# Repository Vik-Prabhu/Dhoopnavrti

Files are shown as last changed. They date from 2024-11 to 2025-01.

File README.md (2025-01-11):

# Dhoopnavarti
Project for a Ayurvedic Medical Ear cleaning device. This device needed temperature and pressure to be monitored and displayed on an oled display. We used STM32L432 MCU for this purpose. Along with these sensores we made a battery monitoring system with the MCU by reading analog values from the battery and displaying it on the oled. The device also readed a charging port of a lighter and the battery for which we used a battery charger with USB. This Repo Includes the PCB designs of the project.

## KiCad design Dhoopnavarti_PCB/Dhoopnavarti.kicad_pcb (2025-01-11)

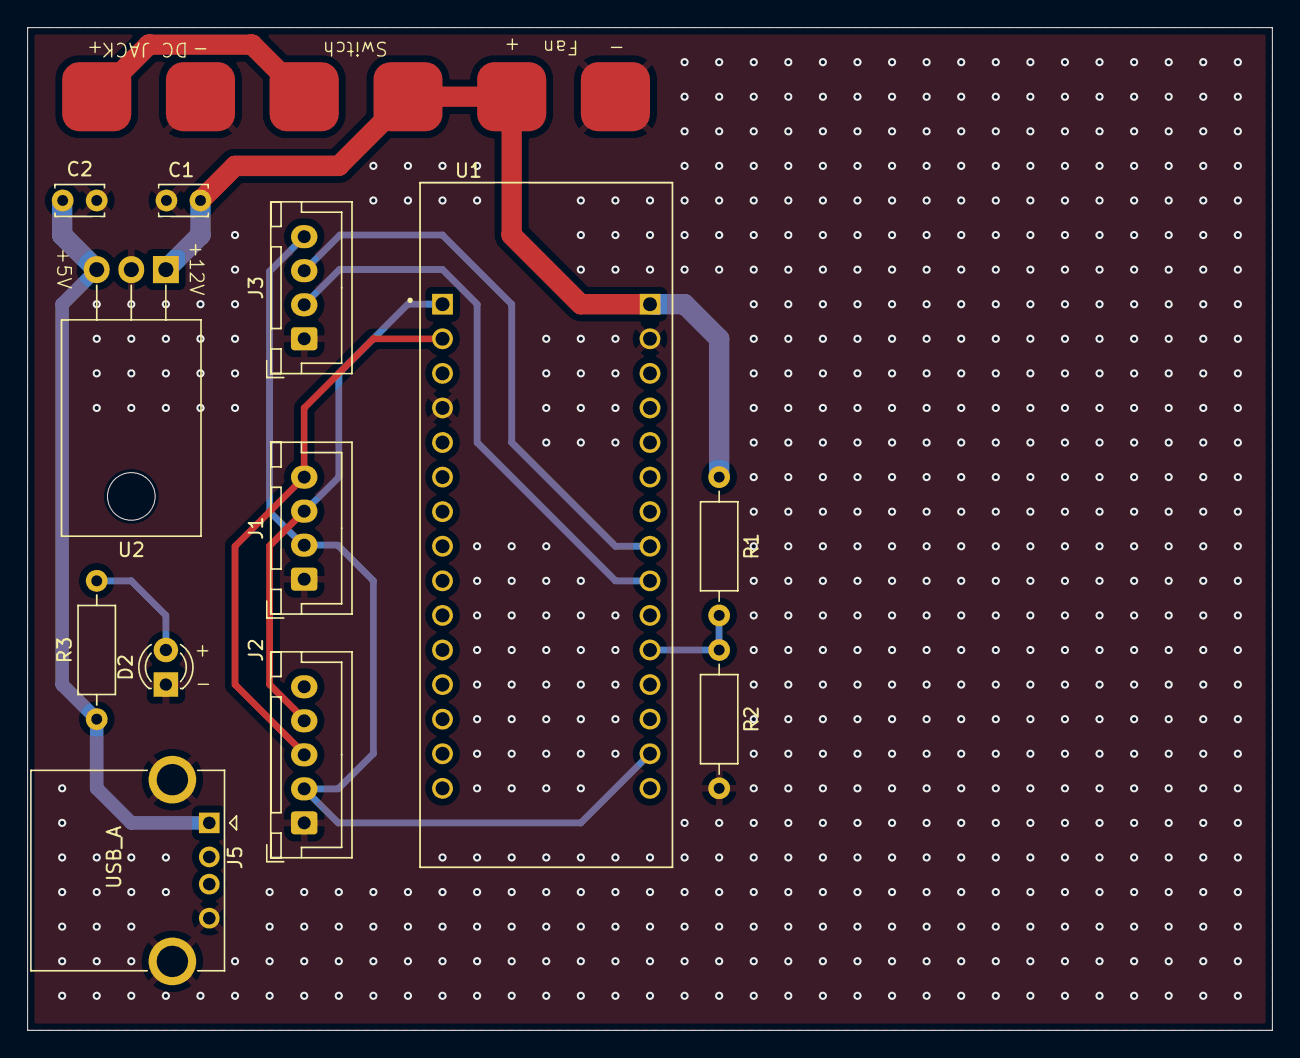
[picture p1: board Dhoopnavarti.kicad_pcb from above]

Board: 2 copper layers, 91.4 x 73.7 mm, 15 parts (0 on the bottom side), 11 nets.

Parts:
C1: 330nF; C_Disc_D3.4mm_W2.1mm_P2.50mm
C2: 100nF; C_Disc_D3.4mm_W2.1mm_P2.50mm
D2: LED; LED_D3.0mm
DC JACK: Screw_Terminal_01x02; Wire_Pad
Fan: Screw_Terminal_01x02; Wire_Pad
J1, J3: Conn_01x04_Pin; JST_XH_B4B-XH-A_1x04_P2.50mm_Vertical
J2: Conn_01x05_Pin; JST_XH_B5B-XH-A_1x05_P2.50mm_Vertical
J5: USB_A; USB_A_Kycon_KUSBX-AS1N-B_Horizontal
R1, R2: R_US; R_Axial_DIN0207_L6.3mm_D2.5mm_P10.16mm_Horizontal
R3: 220; R_Axial_DIN0207_L6.3mm_D2.5mm_P10.16mm_Horizontal
Switch: Screw_Terminal_01x02; Wire_Pad
U1: NUCLEO-L432KC; MODULE_NUCLEO-L432KC
U2: LM7805_TO220; TO-220-3_Horizontal_TabDown

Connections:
+3.3V: J1.2, J2.2, J3.4, U1.CN4_14 (+3V3)
+5V: C2.1, J5.1 (VBUS), R3.1, U2.3 (VO)
+12V: C1.1, Fan.1, R1.1, Switch.2, U1.CN4_1 (VIN), U2.1 (VI)
Battery_+12V: DC JACK.1, Switch.1
GND: C1.2, C2.2, D2.1 (K), DC JACK.2, Fan.2, J1.1, J2.1, J3.1, J5.4 (GND), J5.5 (Shield), R2.2, U1.CN3_4 (GND_CN3), U1.CN4_2 (GND_CN4), U2.2 (GND)
unnamed: D2.2 (A), R3.2
unnamed: R1.2, R2.1, U1.CN4_11 (PA1)
OUT: J3.3, U1.CN4_8 (PA5)
SCK: J3.2, U1.CN4_9 (PA4)
SCL: J1.3, J2.4, U1.CN3_1 (PA9)
SDA: J1.4, J2.3, U1.CN3_2 (PA10)

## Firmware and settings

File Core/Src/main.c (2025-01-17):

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
/* Includes ------------------------------------------------------------------*/
#include "main.h"

/* USER CODE BEGIN Includes */
#include "tmp117.h"
#include "ssd1306.h"
#include "ssd1306_conf.h"
#include "ssd1306_tests.h"
#include "ssd1306_fonts.h"
#include <stdio.h>
#include <string.h>
/* USER CODE END Includes */

/* USER CODE BEGIN PD */
#define HX710B_DATA_GPIO_Port OUT_GPIO_Port
#define HX710B_DATA_Pin OUT_Pin
#define HX710B_CLK_GPIO_Port SCK_GPIO_Port
#define HX710B_CLK_Pin SCK_Pin
/* USER CODE END PD */

ADC_HandleTypeDef hadc1;

I2C_HandleTypeDef hi2c1;
I2C_HandleTypeDef hi2c3;

UART_HandleTypeDef huart2;

/* USER CODE BEGIN PV */
#define TMP117_ADDR          0x48 << 1     // TMP117 address with R/W bit
#define TMP117_TEMP_REG      0x00          // Temperature register
#define TMP117_CONFIG_REG    0x01          // Configuration register

// TMP117 configuration values
#define TMP117_CONFIG_VALUE  0x0220
/* USER CODE END PV */

void SystemClock_Config(void);
static void MX_GPIO_Init(void);
static void MX_I2C1_Init(void);
static void MX_USART2_UART_Init(void);
static void MX_ADC1_Init(void);
static void MX_I2C3_Init(void);
/* USER CODE BEGIN 0 */
// TMP117 Initialization
HAL_StatusTypeDef TMP117_Init(void) {
	uint8_t config_data[3];
	config_data[0] = TMP117_CONFIG_REG;               // Register pointer
	config_data[1] = (TMP117_CONFIG_VALUE >> 8) & 0xFF; // MSB of config
	config_data[2] = TMP117_CONFIG_VALUE & 0xFF;       // LSB of config

	// Write to the configuration register
	return HAL_I2C_Master_Transmit(&hi2c1, TMP117_ADDR, config_data, 3,
			HAL_MAX_DELAY);
}

// Read temperature from TMP117
HAL_StatusTypeDef TMP117_ReadTemperature(float *temperature) {
	uint8_t temp_data[2];
	int16_t raw_temp;

	// Request 2 bytes from temperature register
	temp_data[0] = TMP117_TEMP_REG;
	if (HAL_I2C_Master_Transmit(&hi2c1, TMP117_ADDR, temp_data, 1,
			HAL_MAX_DELAY) != HAL_OK) {
		return HAL_ERROR;  // Error in sending data
	}

	// Receive 2 bytes of temperature data
	if (HAL_I2C_Master_Receive(&hi2c1, TMP117_ADDR, temp_data, 2, HAL_MAX_DELAY)
			!= HAL_OK) {
		return HAL_ERROR;  // Error in receiving data
	}

	// Combine the two bytes to form a 16-bit signed integer
	raw_temp = (int16_t) ((temp_data[0] << 8) | temp_data[1]);

	// Convert to Celsius based on TMP117 resolution (0.0078125 °C per LSB)
	*temperature = raw_temp * 0.0078125;

	return HAL_OK;
}
int _write(int file, char *ptr, int len) {
	int DataIdx;
	for (DataIdx = 0; DataIdx < len; DataIdx++) {
		ITM_SendChar(*ptr++);
	}
	return len;
}

long readHX710B() {
	// Wait until data line is low (indicating data is ready)
	while (HAL_GPIO_ReadPin(HX710B_DATA_GPIO_Port, HX710B_DATA_Pin))
		;

	long result = 0;

	// Read 24 bits from the sensor
	for (int i = 0; i < 24; i++) {
		// Set clock high and then low with small delay for timing
		HAL_GPIO_WritePin(HX710B_CLK_GPIO_Port, HX710B_CLK_Pin, GPIO_PIN_SET);
//        delay_us(1);  // 1 microsecond delay;
//        HAL_Delay(1);
		HAL_GPIO_WritePin(HX710B_CLK_GPIO_Port, HX710B_CLK_Pin, GPIO_PIN_RESET);
//        delay_us(1);  // 1 microsecond delay

		// Shift result left and read data bit
		result = result << 1;
		if (HAL_GPIO_ReadPin(HX710B_DATA_GPIO_Port, HX710B_DATA_Pin)) {
			result++;
		}
	}

	// Convert to two's complement if needed
	result = result ^ 0x800000;

	// Pulse the clock line 3 times to initiate the next reading
	for (char i = 0; i < 3; i++) {
		HAL_GPIO_WritePin(HX710B_CLK_GPIO_Port, HX710B_CLK_Pin, GPIO_PIN_SET);
//        delay_us(1);  // Small delay
//        HAL_Delay(1);
		HAL_GPIO_WritePin(HX710B_CLK_GPIO_Port, HX710B_CLK_Pin, GPIO_PIN_RESET);
//        delay_us(1);  // Small delay
	}

	return result;
}
float mapVoltageToPercentage(float voltage, float minVoltage, float maxVoltage) {
    // Ensure voltage stays within the specified range
    if (voltage < minVoltage) voltage = minVoltage;
    if (voltage > maxVoltage) voltage = maxVoltage;

    // Map the voltage to a percentage
    return ((voltage - minVoltage) / (maxVoltage - minVoltage)) * 100.0;
}
float batterymonitor() {
// Poll for conversion completion and check if the ADC data is ready
	HAL_ADC_Start(&hadc1);
	if (HAL_ADC_PollForConversion(&hadc1, HAL_MAX_DELAY) == HAL_OK) {
		// Get the analog value
		uint32_t adcValue = HAL_ADC_GetValue(&hadc1);

		// Convert ADC value to voltage (assuming 12-bit resolution and 3.3V reference)
		float voltage = (adcValue * 5.0f) / 1023.0f;

		// Print or use the voltage value
		return voltage / (0.4);
	}
	return 0;
}

/* USER CODE END 0 */

/**
  * @brief  The application entry point.
  * @retval int
  */
int main(void)
{

  /* MCU Configuration--------------------------------------------------------*/

  /* Reset of all peripherals, Initializes the Flash interface and the Systick. */
  HAL_Init();

  /* Configure the system clock */
  SystemClock_Config();

  /* Initialize all configured peripherals */
  MX_GPIO_Init();
  MX_I2C1_Init();
  MX_USART2_UART_Init();
  MX_ADC1_Init();
  MX_I2C3_Init();
  /* USER CODE BEGIN 2 */
	float temp = 0.0;
	char message[100];
	//ssd1306_Init();
	//TMP117_set_Configuration(hi2c1,0x20,0x02);
	//TMP117_Initialization_DEFAULT(hi2c1);
	// TMP117_set_Temperature_Offset(hi2c1,0x60,0x00);
	HAL_Delay(2);
	ssd1306_Init();
	ssd1306_Fill(Black);
//  HAL_ADC_Start(&hadc1);

  /* USER CODE END 2 */

  /* Infinite loop */
  /* USER CODE BEGIN WHILE */
	while (1) {
		TMP117_ReadTemperature(&temp) ;
		HAL_Delay(100);
		ssd1306_Fill(Black);
		ssd1306_SetCursor(0, 4);
		sprintf(message, "Temp: %.4fC\n", temp);
		ssd1306_WriteString(message, Font_7x10, White);
		ssd1306_SetCursor(0, 4 + 20);
		sprintf(message, "Pressure: %.2fatm\n", readHX710B()/10000000.0);
		ssd1306_WriteString(message, Font_7x10, White);
		ssd1306_SetCursor(0, 4 + 38);
		float battery = batterymonitor();
		HAL_Delay(100);
		HAL_ADC_Stop(&hadc1);
//	sprintf(message, "Battery Voltage: %.2fV\n", battery-0.889);
//	ssd1306_WriteString(message, Font_6x8, White);

	if((battery-0.889)<11.5){
		sprintf(message, "Battery:%.2f%",mapVoltageToPercentage(battery-0.889,7.4,8));
		HAL_UART_Transmit(&huart2, message, strlen(message), HAL_MAX_DELAY);
		ssd1306_WriteString(message, Font_7x10, White);
	}
	else{
		sprintf(message, "Battery:Full");
		HAL_UART_Transmit(&huart2, message, strlen(message), HAL_MAX_DELAY);
		ssd1306_WriteString(message, Font_7x10, White);
	}
		ssd1306_UpdateScreen();

    /* USER CODE END WHILE */

    /* USER CODE BEGIN 3 */
	}
  /* USER CODE END 3 */
}

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


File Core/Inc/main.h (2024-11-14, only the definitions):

#define MCO_Pin GPIO_PIN_0
#define MCO_GPIO_Port GPIOA
#define VCP_TX_Pin GPIO_PIN_2
#define VCP_TX_GPIO_Port GPIOA
#define VCP_RX_Pin GPIO_PIN_3
#define VCP_RX_GPIO_Port GPIOA
#define SCK_Pin GPIO_PIN_4
#define SCK_GPIO_Port GPIOA
#define OUT_Pin GPIO_PIN_5
#define OUT_GPIO_Port GPIOA
#define SWDIO_Pin GPIO_PIN_13
#define SWDIO_GPIO_Port GPIOA
#define SWCLK_Pin GPIO_PIN_14
#define SWCLK_GPIO_Port GPIOA

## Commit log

2024-11-11 Pressure Sensor v0.1
2024-11-14 Sensor Fusion
2024-11-14 Sensor Fusion v1.00
2024-11-15 Battery Monitor v1.01
2025-01-05 PCB File Added
    [Dhoopnavarti.kicad_pcb, Dhoopnavarti.kicad_sch]
2025-01-11 Routing v1
    [Dhoopnavarti.kicad_pcb, Dhoopnavarti.kicad_sch]
2025-01-17 Battery Monitor v2

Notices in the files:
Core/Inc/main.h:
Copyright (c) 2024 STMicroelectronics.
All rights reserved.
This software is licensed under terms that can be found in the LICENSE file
